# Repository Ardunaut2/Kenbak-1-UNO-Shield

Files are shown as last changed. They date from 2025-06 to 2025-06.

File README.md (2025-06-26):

# Kenbak-1 UNO Shield
Adapting the Mark Wilson's kenbakuino (https://github.com/funnypolynomial/Kenbakuino) to run on the Arduino UNO.
Unlike the original design, which used shift registers, this version leverages interrupts and multiplexing to refresh the LEDs and read button inputs.
This approach significantly reduces the number of required components.

<div style="text-align: center;">
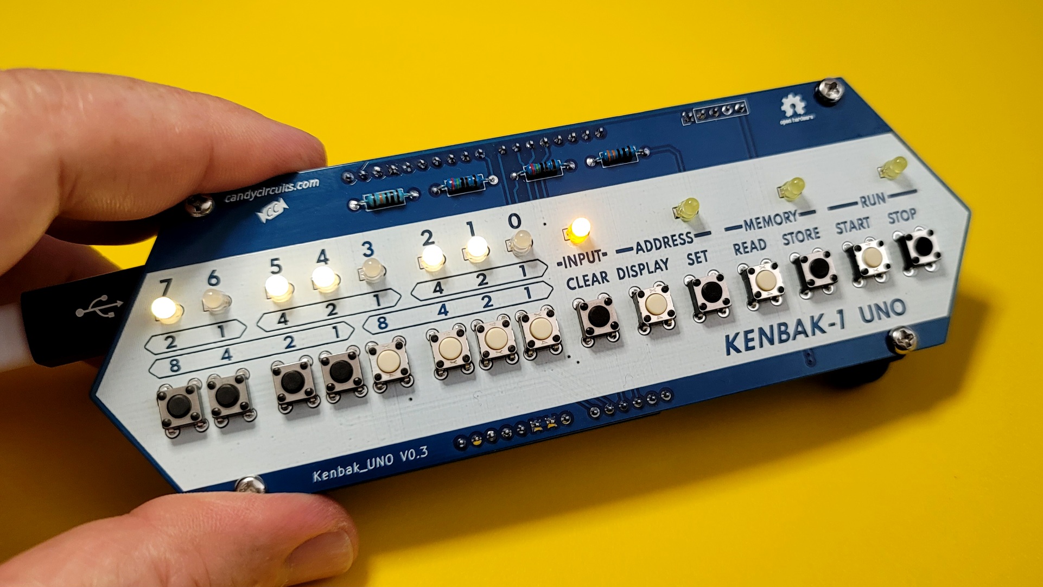
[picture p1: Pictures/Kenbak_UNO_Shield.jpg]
  
</div>
Kenbak-1 Arduino UNO Shield

<div style="text-align: center;">
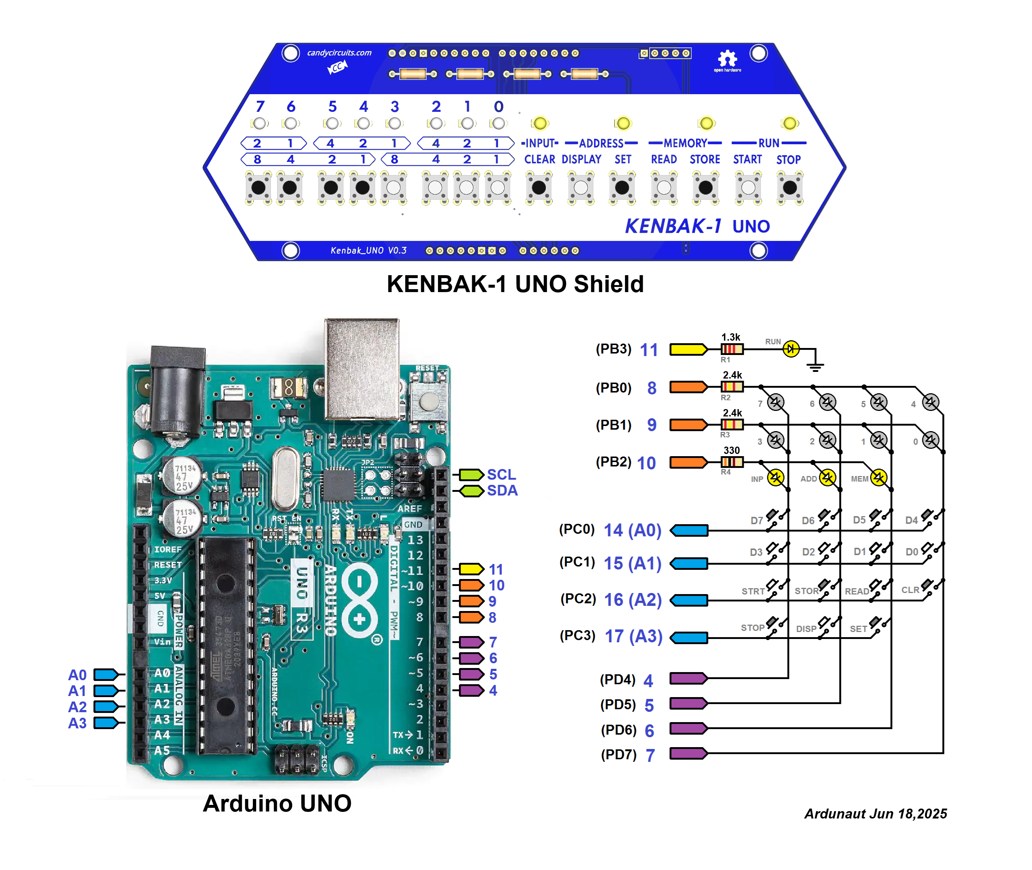
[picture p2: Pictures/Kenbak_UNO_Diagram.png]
  
</div>
Arduino UNO diagram

<div style="text-align: center;">
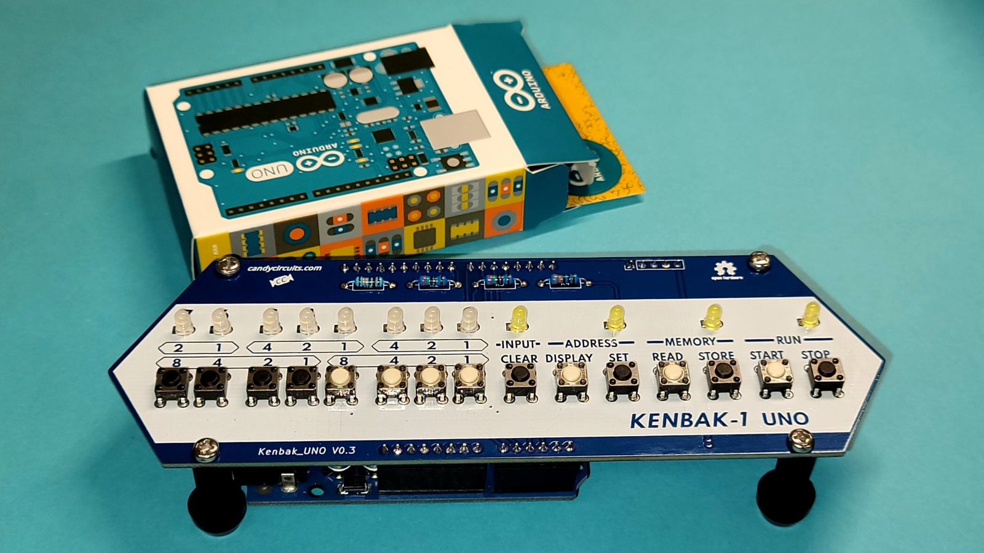
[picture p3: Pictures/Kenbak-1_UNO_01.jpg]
  
</div>

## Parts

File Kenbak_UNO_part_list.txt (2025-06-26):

Kenbak UNO Part List:

Item  Description                                                        Qty
 1.- Resistor 1/4W 1.3k 5% (R1) ........................................  1
 2.- Resistor 1/4W 2.4k 5% (R2,R3) .....................................  2
 3.- Resistor 1/4W 330 5% (R4) .........................................  1
 3.- 3mm Warm White Diffused led (D1-D8) ...............................  8
 5.- 3mm Yellow Diffused led (D9-D12) ..................................  4
 6.- Same Sky TS02-66-43-BK-100-LCR-D Tactile Switch 6x6mm 4.3mm Height 
     100gr actuation force, Black (SW1-SW4, SW9, SW11, SW13, SW15)......  8
 7.- OMRON B3F-1000 Tactile Switch 6x6mm 4.3mm Height
     100gr actuation force, White (SW5-SW8, SW10, SW12, SW14) ..........  7
 8.- 5-pin header ......................................................  1
 9.- 6-pin header ......................................................  1
10.- 8-pin header ......................................................  2
11.- 10-pin header .....................................................  1
12.- DS3231 Real Time Clock Module (J1) ................................  1
11.- Arduino UNO Rev3 or compatible ....................................  1

Mechanical Parts (Optional Simple four-legged base):
 1.- M3 x 15mm Female-Female Hex Thread Nylon Spacer ...................  4
 2.- 7/16" (11mm) W x 1/4" (6mm) Round Rubber Feet Bumpers .............  4
 3.- M3 x 6mm Pan Head Machine Screw, Stainless Steel ..................  8

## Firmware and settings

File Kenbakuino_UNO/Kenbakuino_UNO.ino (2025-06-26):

/* Kenbakuino_UNO.ino  Ardunaut Jun 26,2025
 *   -Replacing       by
 *      Pins.h        Pins2.h
 *      LEDS.h        LEDS2.h
 *      LEDS.cpp      LEDS2.cpp
 *      Buttons.h     Buttons2.h
 *      Buttons.cpp   Buttons2.cpp
 *   -Added in main sketch:
 *      TIMER1 Interrupt Service Routine to read buttons and update leds.
*/

// ==================================================================
// ==================================================================
//      K E N B A K u i n o
//      Mark Wilson 2011
//  Software emulation of a KENBAK-1.
//  Released under Creative Commons Attribution, CC BY
//  (kiwimew at gmail dot com)
//  Sep 2011: Initial version.
//  Jan 2012: Changes to compile under v1.0 if the IDE (Arduino.h, changes to Wire)
//  May 2014: Corrected control switch order in schematic, 
//            typos in documents (no code changes)
//  Jun 2015: Changes to compile under v1.6.4 if the IDE, (#define for deprecated prog_uchar)  
//  Dec 2018: Corrected SDA/SCL pins, clarified that RTC is a DS1307 module/breakout (i.e. with XTAL)
//            GitHub. Serial read/write memory
//  May 2019: Added Auto-run program at start-up
//            Added Clock consts for no RTC or RTC with no SRAM
//  Jun 2019: Added system extensions to read/write EEPROM
//  May 2021: Fixed right-shift sign extension and issues with multi-bit roll instructions (see CPU_LEGACY_SHIFT_ROLL)
//  Sep 2022: Fixed program counter increment to happen after instruction executed (see CPU_LEGACY_PROGRAM_COUNTER)
//  Nov 2024: Turn RUN LED off when HALT encountered or STOP pressed (see MCP_LEGACY_RUN_LED)
// ==================================================================

// WTF.  We need to include these in the "main sketch" if we want to include them in "tabs"?
#include <Arduino.h>
#include <Wire.h>

#include "PINS2.h"
#include "Config.h"
#include "Clock.h"
#include "LEDS2.h"
#include "Buttons2.h"
#include "CPU.h"
#include "MCP.h"
#include "Memory.h"

#define COLMASK 0b11110000  //(to be used in the PORTD access)

/*------- KeyState key bits, following ken_pins.txt  order ------------------- */
enum {key0, key1, key6, key7, key4, key5, key2, key3,
  keyStop, keyStart, noKey, keyClear, keyDisplay, keySet, keyRead, keyStore
};

/*------- ledsData bits, following ken_pins.txt  order ------------------- */
 enum {led0, led1, led2, led3, led4, led5, led6, led7,
  };

/*------- ledsControl bits, following MCP.h  order ------------------- */
 enum {inputLed, addressLed, memoryLed, runLed,  noneLed
  };

 byte ledsData = 0x00 ;              // declared as extern in LEDS2.h
 byte ledsControl = 0x00 ;           // declared as extern in LEDS2.h
 volatile word keysState = 0xFFFF;   // declared as extern in Buttons2.h
 byte counter=0;
 
ExtendedCPU cpu = ExtendedCPU();

void setup() 
{
  Serial.begin(38400);
  PORTD = PORTD & ~COLMASK;      // all column data LOW.).  
  pinMode(LEDS1, OUTPUT);
  pinMode(LEDS2, OUTPUT);
  pinMode(LEDS3, OUTPUT);
  pinMode(KEYS1, INPUT_PULLUP);
  pinMode(KEYS2, INPUT_PULLUP);
  pinMode(KEYS3, INPUT_PULLUP);
  pinMode(KEYS4, INPUT_PULLUP);
  pinMode(RUNLED, OUTPUT);      // Not needed, uses analogWrite()
  
  cli();                   // Disable interrupts ---------------------------------
// Set TIMER1 interrupts at 1.244KHz (to avoid flickering leds at max count speed):
  TCCR1A = 0;              // set entire TCCR1A register to 0
  TCCR1B = 0;              // same for TCCR1B
  TCNT1  = 0;              //initialize counter value to 0
//  OCR1A = 249;             // = 16.000.000 / (1000*64) - 1 (1KHz)  // Sets compare match register
  OCR1A = 200;             // = 16.000.000 / (1244*64) - 1 (1.244KHz)  // Sets compare match register
//  OCR1A = 124;             // = 16.000.000 / (2000*64) - 1 (2KHz)  // Sets compare match register
  TCCR1B |= (1 << WGM12);              // Turns on CTC mode.
  TCCR1B |= (1 << CS11) | (1 << CS10); // Sets CS11 and CS10 bits for 64 prescaler.
  TIMSK1 |= (1 << OCIE1A);             // Enables the timer compare interrupt.

  sei();                   // Enable interrupts ---------------------------------
  delay(10);               // time to refresh keysState     


  clock.Init();
  buttons.Init();
  config.Init();
  leds.Init();
  cpu.Init();
  memory.Init();
  mcp.Init();
}
 
void loop() 
{
  mcp.Loop();
}

/*------------------------------------------------------------------------------
TIMER1 Interrupt Service Routine
------------------------------------------------------------------------------*/
ISR(TIMER1_COMPA_vect){            //timer1 interrupt 1KHz
static byte column = 0b00010000;   //pointing to the first column (left side)

  digitalWrite(LEDS1,LOW);
  digitalWrite(LEDS2,LOW);
  digitalWrite(LEDS3,LOW);
  
  if(column == 0b10000000) column = 0b00010000; //points to the first column
  else column = column << 1;   // point to next column
  DDRD = DDRD & ~COLMASK;      // sets all column pins as inputs
  DDRD = PORTD | column;       // select the new column as output LOW.

  // here update the leds values and read the pushbuttons:
  if (bitRead(column, 4)== 1){
    bitWrite(keysState, key7, !digitalRead(KEYS1));
    bitWrite(keysState, key3, !digitalRead(KEYS2));
    bitWrite(keysState, keyStart, !digitalRead(KEYS3));
    bitWrite(keysState, keyStop, !digitalRead(KEYS4));
    digitalWrite(LEDS1,bitRead(ledsData, led7));
    digitalWrite(LEDS2,bitRead(ledsData, led3));
    digitalWrite(LEDS3,bitRead(ledsControl, inputLed));
  }
  if (bitRead(column, 5)== 1){
    bitWrite(keysState, key6, !digitalRead(KEYS1));
    bitWrite(keysState, key2, !digitalRead(KEYS2));
    bitWrite(keysState, keyStore, !digitalRead(KEYS3));
    bitWrite(keysState, keyDisplay, !digitalRead(KEYS4));
    digitalWrite(LEDS1,bitRead(ledsData, led6));
    digitalWrite(LEDS2,bitRead(ledsData, led2));
    digitalWrite(LEDS3,bitRead(ledsControl, addressLed));
  }
  if (bitRead(column, 6)== 1){
    bitWrite(keysState, key5, !digitalRead(KEYS1));
    bitWrite(keysState, key1, !digitalRead(KEYS2));
    bitWrite(keysState, keyRead, !digitalRead(KEYS3));
    bitWrite(keysState, keySet, !digitalRead(KEYS4));
    digitalWrite(LEDS1,bitRead(ledsData, led5));
    digitalWrite(LEDS2,bitRead(ledsData, led1));
    digitalWrite(LEDS3,bitRead(ledsControl, memoryLed));    
  }
  if (bitRead(column, 7)== 1){
    bitWrite(keysState, key4, !digitalRead(KEYS1));
    bitWrite(keysState, key0, !digitalRead(KEYS2));
    bitWrite(keysState, keyClear, !digitalRead(KEYS3));
    digitalWrite(LEDS1,bitRead(ledsData, led4));
    digitalWrite(LEDS2,bitRead(ledsData, led0));

    if(bitRead(ledsControl,runLed))
    {
      // the Run LED can do PWM, use the upper 4 bits.
      analogWrite(RUNLED,(0xFF-(ledsControl & 0xF0)));    // intensity
    }
    else
    {
      digitalWrite(RUNLED, LOW);      // Turn off  RUN Led.
    }
  }

}

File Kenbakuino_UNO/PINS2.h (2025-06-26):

#ifndef PINS2_H
#define PINS2_H

// I2C (Real Timne Clock) Pin assignments:
#define PIN_RTC_SDA	A4
#define PIN_RTC_SCL	A5

#define RUNLED    11        // PWM control of the RUN led.

#define LEDS1      8
#define LEDS2      9
#define LEDS3     10

#define KEYS1     14        // A0
#define KEYS2     15        // A1
#define KEYS3     16        // A2
#define KEYS4     17        // A3

#endif
